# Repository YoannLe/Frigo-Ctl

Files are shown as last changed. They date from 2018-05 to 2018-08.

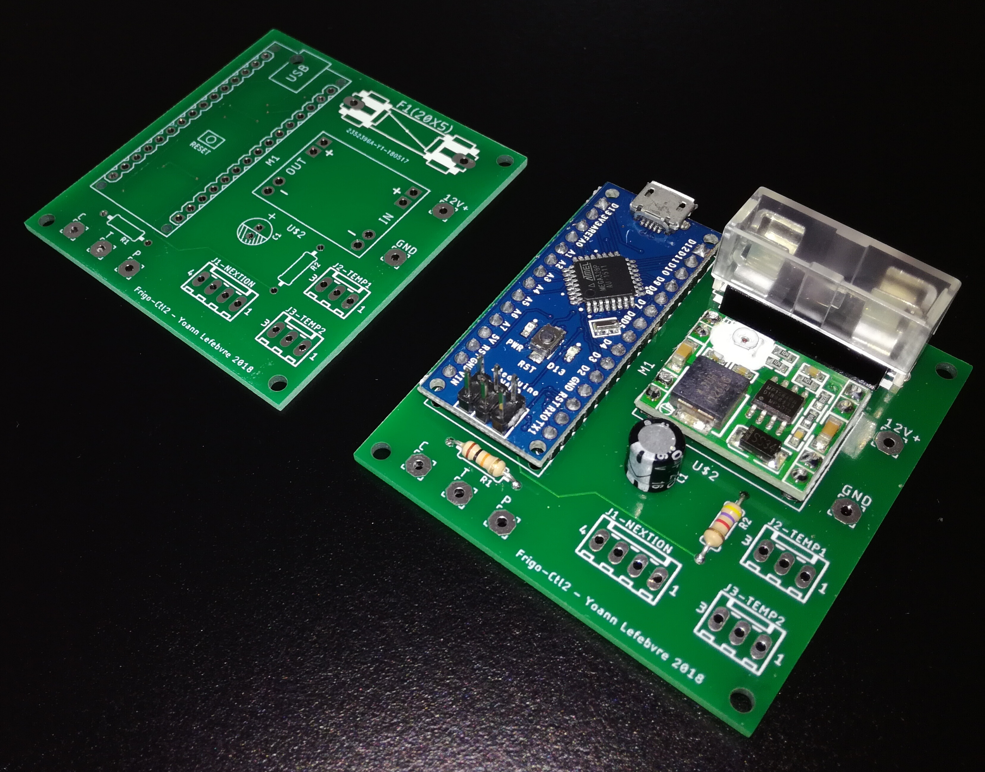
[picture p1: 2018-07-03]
Photos/IMG_20180608_055805.jpg

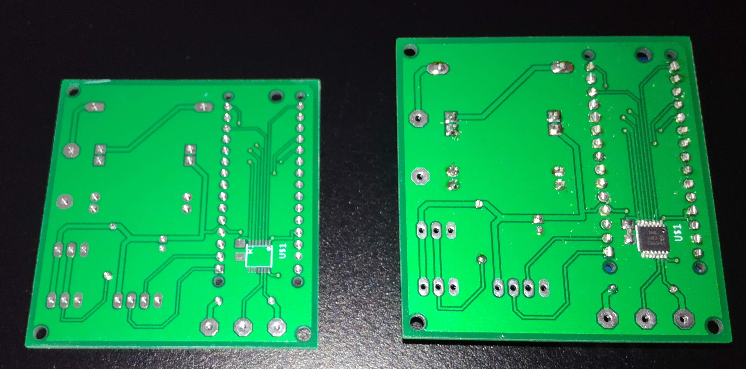
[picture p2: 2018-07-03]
Photos/IMG_20180602_103453.jpg

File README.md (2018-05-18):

# Frigo-Ctl
Arduino controller and thermostat with touch screen for 12V Fridge Compressor. Boat, RV, motorhome. To drive Danfoss, SECOP, vitrifrigo, 101N0212 compressors control units.

Compressors RPM, start and stop could be controled by resistors values and mechanical thermostat.

To set the best ratio between compressor speed and cold generation needed, the AOE protocol was developed on high end devices. This project coud genarate AOE control on a standard unit and specials functions like manual boost, graphic touch screen and DS18B20 temperature sensors.

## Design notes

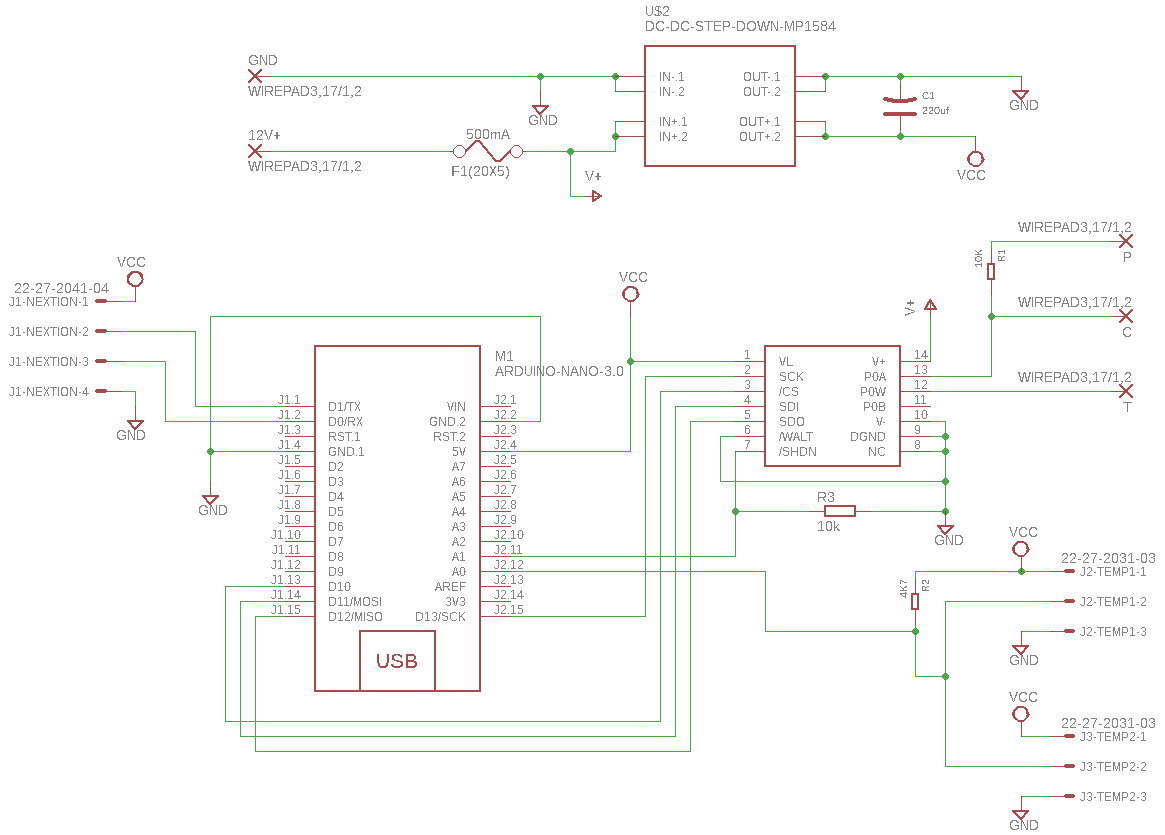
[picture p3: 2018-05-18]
PCB/Frigo-Ctl/Schematic.png

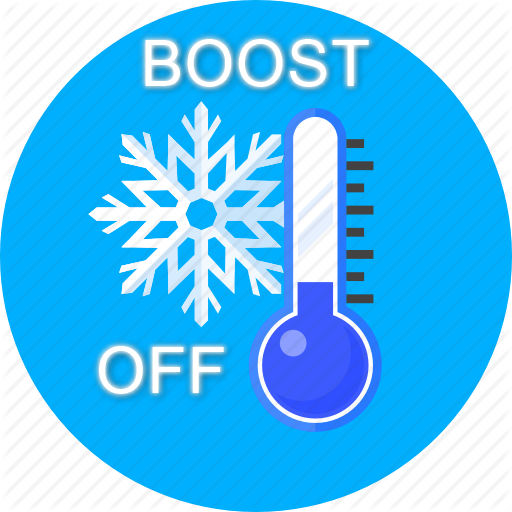
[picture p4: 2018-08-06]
Nextion/Images/Sources/Turbo-OFF.png

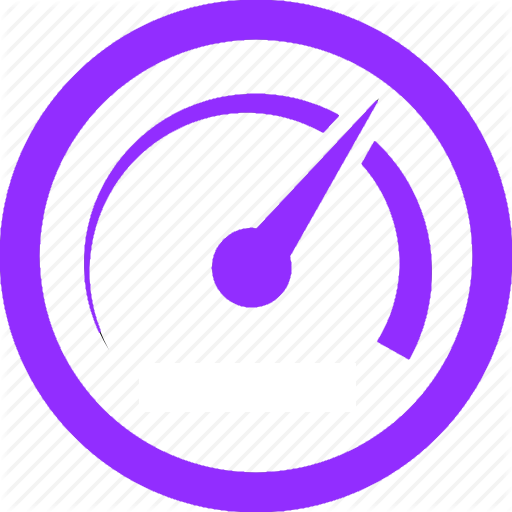
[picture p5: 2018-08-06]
Nextion/Images/Sources/RPM_Gauge-512.png

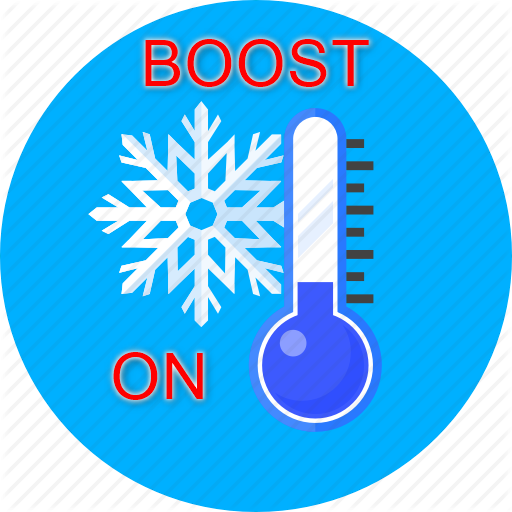
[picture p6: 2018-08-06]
Nextion/Images/Sources/Turbo-ON.png

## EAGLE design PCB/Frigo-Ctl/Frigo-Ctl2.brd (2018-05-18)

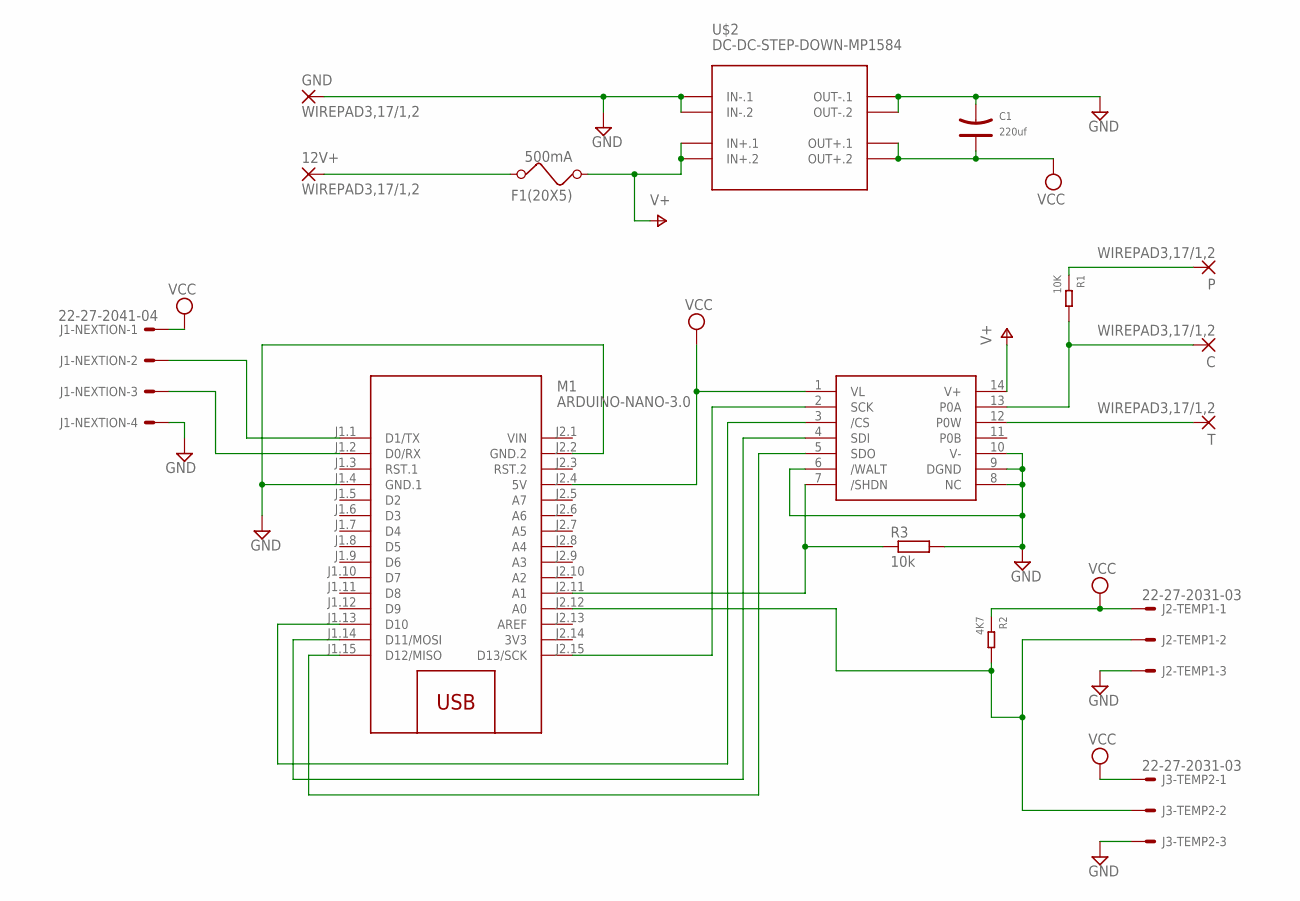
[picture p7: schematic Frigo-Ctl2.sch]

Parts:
12V+: WIREPAD3,17/1,2; 3,17/1,2
C: WIREPAD3,17/1,2; 3,17/1,2
C1: 220uf; PC-D5.3MM
F1(20X5): 500mA; FUSE
GND: WIREPAD3,17/1,2; 3,17/1,2
J1-NEXTION: 22-27-2041-04; 6410-04
J2-TEMP1, J3-TEMP2: 22-27-2031-03; 6410-03
M1: ARDUINO-NANO-3.0
P: WIREPAD3,17/1,2; 3,17/1,2
R1: 10K; PR-D2.3XL6.5MM
R2: 4K7; PR-D2.3XL6.5MM
R3: 10k; R1206
T: WIREPAD3,17/1,2; 3,17/1,2
U$1: MCP41HV51; TSSOP14
U$2: DC-DC-STEP-DOWN-MP1584

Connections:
3V3: M1.J2.14 (3V3)
GND: C1.-, GND.1, J1-NEXTION.4, J2-TEMP1.3, J3-TEMP2.3, M1.J1.4 (GND.1), M1.J2.2 (GND.2), R3.2, U$1.6 (/WALT), U$1.8 (NC), U$1.9 (DGND), U$1.10 (V-), U$2.IN-.1, U$2.IN-.2, U$2.OUT-.1, U$2.OUT-.2
unnamed: 12V+.1, F1(20X5).2
unnamed: M1.J2.11 (A1), R3.1, U$1.7 (/SHDN)
unnamed: J1-NEXTION.2, M1.J1.1 (D1/TX)
unnamed: J1-NEXTION.3, M1.J1.2 (D0/RX)
unnamed: C.1, R1.2, U$1.13 (P0A)
unnamed: P.1, R1.1
unnamed: M1.J1.13 (D10), U$1.3 (/CS)
unnamed: T.1, U$1.12 (P0W)
unnamed: M1.J2.15 (D13/SCK), U$1.2 (SCK)
unnamed: M1.J1.15 (D12/MISO), U$1.5 (SDO)
unnamed: M1.J1.14 (D11/MOSI), U$1.4 (SDI)
unnamed: J2-TEMP1.2, J3-TEMP2.2, M1.J2.12 (A0), R2.2
V+: F1(20X5).1, U$1.14 (V+), U$2.IN+.1, U$2.IN+.2
VCC: C1.+, J1-NEXTION.1, J2-TEMP1.1, J3-TEMP2.1, M1.J2.4 (5V), R2.1, U$1.1 (VL), U$2.OUT+.1, U$2.OUT+.2
VIN: M1.J2.1 (VIN)

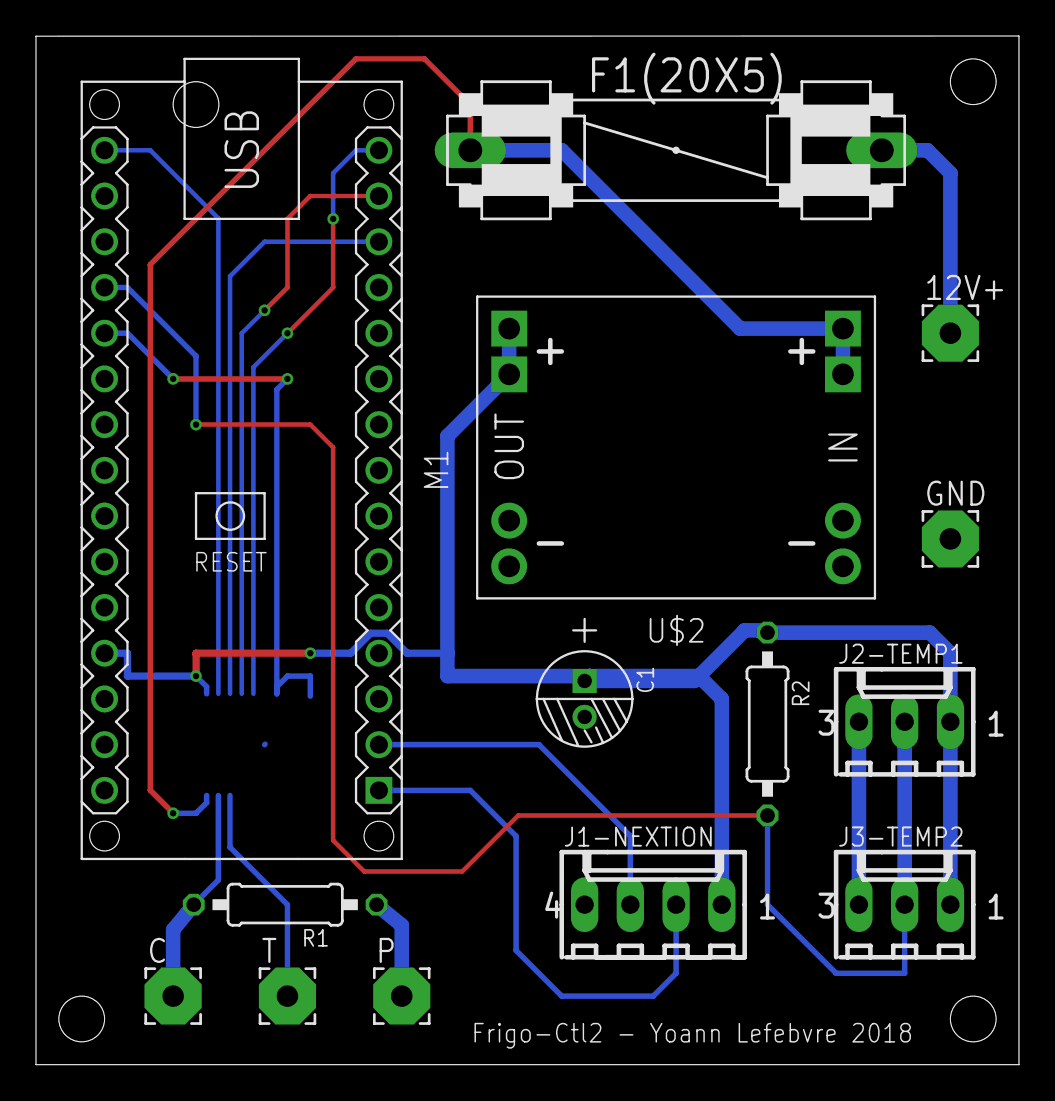
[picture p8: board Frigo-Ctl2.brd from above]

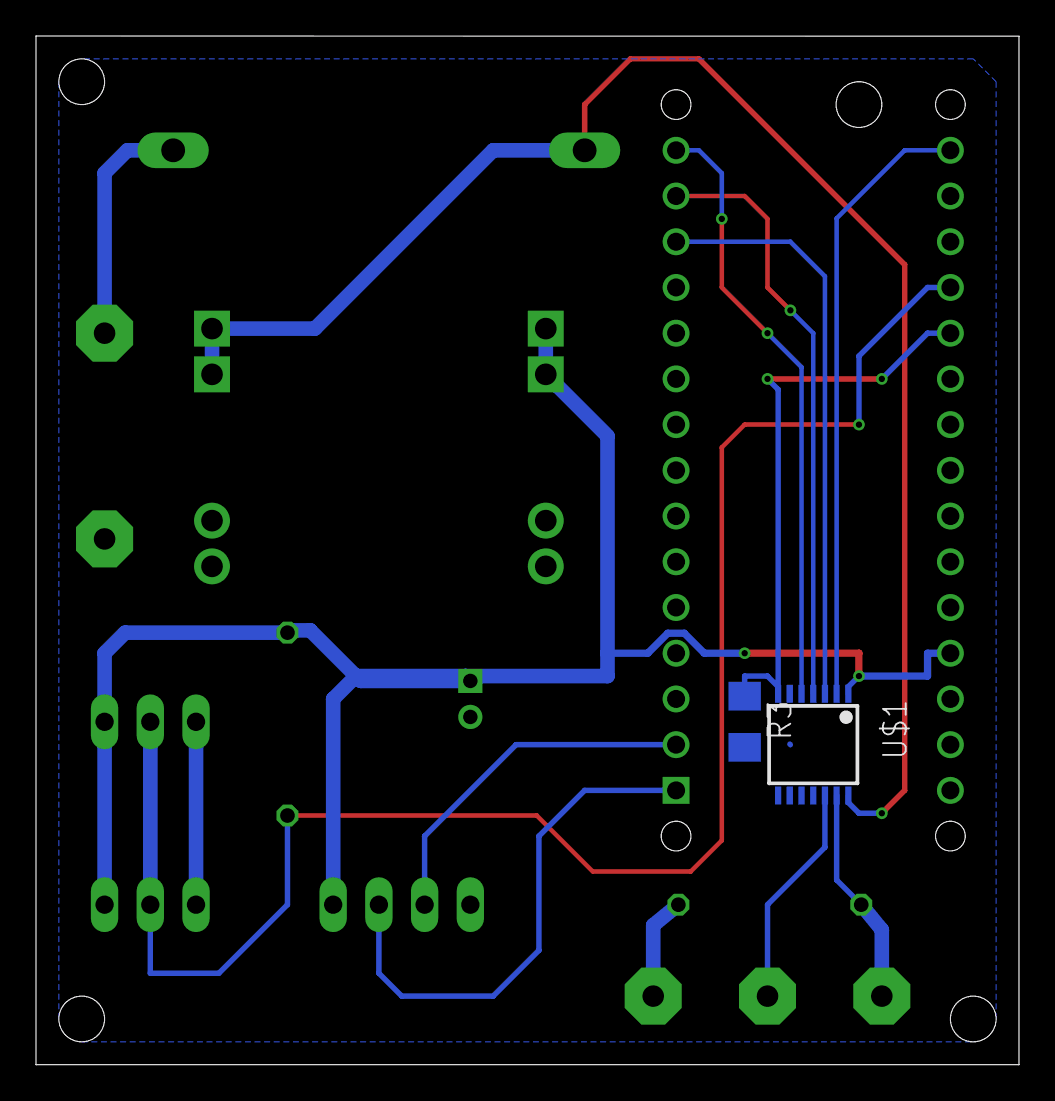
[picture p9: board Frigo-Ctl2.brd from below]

Board: 2 copper layers, 54.6 x 57.1 mm, 16 parts (2 on the bottom side), 15 nets.

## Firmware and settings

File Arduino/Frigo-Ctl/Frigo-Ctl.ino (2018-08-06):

// Disconnect Nextion to upload sketch to arduino.
// Hardware serial used, permits to trace serial coms with nextion via usb port of arduino and serial monitor
// can debug with NEXTION Simulator/Editor through Arduino USB
// Nextion charset ISO 8859-1 (latin-1)

#include <SimpleTimer.h>

//NEXTION

#include <Nextion.h>
#include <NextionPage.h>
#include <NextionVariableNumeric.h>
#include <NextionText.h>
#include <NextionNumber.h>
#include <NextionWaveform.h>
#include <NextionDualStateButton.h>
#include <SPI.h>
#include <OneWire.h>

#define NEXTION_PORT Serial

Nextion nex(NEXTION_PORT);

//NEXTION vars:
//NextionVariableNumeric varNexTempSet(nex, 0, 7, "TempSet"); //page 0, id 7
NextionVariableNumeric varVisWave(nex, 0, 26, "visWave"); //visWave id 26 -> check if waveform is visible

//NEXTION TXT:
NextionText txtNexTempFrig(nex, 0, 9, "TempFrigTxt");
NextionText txtNexTempCong(nex, 0, 10, "TempCongTxt");
NextionText txtNexTempSet(nex, 0, 8, "TempSetTxt");
//n0 id 2 : rpm
NextionNumber numNexRPM(nex, 0, 2, "n0");
//waveform ID 13 name s0
NextionWaveform graph(nex, 0, 13, "s0");
//Boost button state
NextionDualStateButton boostBt(nex, 0, 3, "bt0");

//Vars et const
float tempFrigDS;
float tempCongDs;
float tempSet = 4;
// Compressor entre 2000 et 3500
float   compresRPM=0;
float   compresRPMStart = 2500;
#define compresRPM_MIN 2200
#define compresResistorAt_MIN 0
#define compresRPM_MAX 3500
#define compresResistorAt_MAX 1523
#define potRw 180 // RW value depends on T°, Vres and Iw
#define coefRPM_Res (compresResistorAt_MAX-compresResistorAt_MIN)/(compresRPM_MAX-compresRPM_MIN)

#define compRPMRampSpeed 9.4
#define compresRPMafterBoost 2500
bool  boostUsed = 0;

//timer
SimpleTimer timer;

//DS18B20
OneWire  ds(A0);  // on pin A0 (a 4.7K resistor is necessary)
bool dsMesured = 0;
byte dsaddr1[8], dsaddr2[8];

// SPI MCP41HVX1
// MCP41100 connected to  arduino Board
// CS >>> D10
// SCLK >> D13
// DI  >>> D11
// 

byte address = 0x11;
#define CS 10       //D10
#define SHDWN 15    //A1
#define addr  0x00



void setup()
{
  NEXTION_PORT.begin(19200);
  nex.init();
  timer.setInterval(60000, setRPMandGraph); //toutes les minutes vitesse compresseur et graphe
  timer.setInterval(500, sendNex); //toutes les 500ms actualise l'affichage et valeur TempSet
  timer.setInterval(1500, getDsTemperature); //toutes les 1500ms mesure la température ou recupère les valeurs
  
  
  pinMode (CS, OUTPUT);
  pinMode (SHDWN, OUTPUT);
  digitalWrite(SHDWN, LOW); //coupe le compresseur
  
  SPI.begin();

  Serial.begin(19200);
  
  nex.poll();
  
}

void loop() {
  //toutes les minutes vitesse compresseur et graphe
  //toutes les 500ms actualise l'affichage
  //toutes les 1500ms mesure la température ou recupère les valeurs
  timer.run();

}


void setRPMandGraph()
{
  double graphVal;
  float tempRef;
  
   //Gestion vitesse compresseur et graphique toutes les minutes
  if(compresRPM == 0)
    // Compresseur éteint, attendre niveau tempSet+1°C avant start
    {
      tempRef = tempSet+1;
      if(tempFrigDS > tempRef)
      {
        compresRPM = compresRPMStart;
        digitalPotRPMWrite(compresRPM);
        digitalWrite(SHDWN, HIGH); //démarre le compresseur
      }
    }else{
    //Compresseur en route
      if(tempFrigDS > tempSet)
      //si température supérieure à tempsSet
      {
        // Compresseur en fonctionnement, application du ramp dans la limite du max
        if(compresRPM<compresRPM_MAX)
        {
          compresRPM = compresRPM+compRPMRampSpeed;
          digitalPotRPMWrite(compresRPM);
        }
        //activation du boost
        if(boostBt.isActive())
        {
          compresRPM = compresRPM_MAX;
          digitalPotRPMWrite(compresRPM);
          boostUsed =1;
        }else{
          //desactivation du boost
          if(boostUsed)
          {
            compresRPM = compresRPMafterBoost;
            digitalPotRPMWrite(compresRPM);
            boostUsed=0;
          }
        }
      }else{
        //archive rpm de stop - 300 rpm (systeme AOE)
        //sauf si boost, valeur de référence
        if(boostUsed == 1)
        {
          compresRPMStart = compresRPMafterBoost;
          boostUsed =0;
        }else{
          tempRef=compresRPM-300;
          if(tempRef>compresRPM_MIN)
          {
            compresRPMStart = compresRPM-300;
          }else{
            compresRPMStart = compresRPM_MIN;
          }
        }
        //stope le compresseur
        compresRPM=0;
        digitalWrite(SHDWN, LOW); //coupe le compresseur
      }
    }
  
  //actualisation graphique toutes les minutes 220pix
  if(compresRPM>1500)
  {
    graphVal = (compresRPM-1500)/2200;
    graphVal = graphVal*220;
  }else{
    graphVal = 0;
  }
  graph.addValue(0, graphVal);         //RPM max graph 1500 à 3700
  graphVal = tempFrigDS*(220/44)+110;
  if(graphVal > 220)
  {
    graphVal = 220;
  }
  if(graphVal < 0)
  {
    graphVal = 0;
  }
  graph.addValue(1, graphVal);       //Temp Frigo -22 à +22
  graphVal = tempCongDs*(220/44)+110;
  if(graphVal > 220)
  {
    graphVal = 220;
  }
  if(graphVal < 0)
  {
    graphVal = 0;
  }
  graph.addValue(2, graphVal);       //Temp congel
}

float getTempSet()
{
  String tempNex;
  char nexBuffer[10];

  txtNexTempSet.getText(nexBuffer,10);
  nex.poll();
  tempNex=String(nexBuffer);
  if(tempNex.indexOf(char(0xB0)) > -1)
  {
  tempNex.remove(tempNex.indexOf(char(0xB0)));
  }
  if(tempNex.indexOf('C') > -1)
  {
  tempNex.remove(tempNex.indexOf('C'));
  }
  if(tempNex.indexOf(' ') > -1)
  {
  tempNex.remove(tempNex.indexOf(' '));
  }
  return(tempNex.toFloat());
}


void sendNex() 
{
  String tempToNex;
  char nexBuffer[10];
  int visiWave=1;

  nex.poll();
  visiWave=varVisWave.getValue();
  tempSet=getTempSet();
  nex.poll();
  
  if(visiWave == 0)
  {
    numNexRPM.setValue(compresRPM);
        
    tempToNex = String(tempFrigDS,1);
    tempToNex = String(tempToNex + char(0xB0));
    tempToNex = String(tempToNex + "C");
    tempToNex.toCharArray(nexBuffer, 10);
    txtNexTempFrig.setText(nexBuffer);
      
    tempToNex = String(tempCongDs,1);
    tempToNex = String(tempToNex + char(0xB0));
    tempToNex = String(tempToNex + "C");
    tempToNex.toCharArray(nexBuffer, 10);
    txtNexTempCong.setText(nexBuffer);

    nex.refresh("TempCongTxt");
    nex.refresh("TempFrigTxt");
    nex.refresh("n0");
    
    //nex.sendCommand("vis TempCongTxt,1");
    //nex.sendCommand("vis TempFrigTxt,1");
    //nex.sendCommand("vis n0,1"); 
  }else{
    nex.refresh("s0");
  }
  nex.poll();
}

void digitalPotRPMWrite(float comRPM)
{
  //comRPM
  //2000 ->    0 Ohms / 5mA
  //2500 ->  277 Ohms / 4mA
  //3000 ->  692 Ohms / 3mA
  //3500 -> 1523 Ohms / 2mA
  // not linear but not realy a probleam
  // (1523-0)/(3500-2000)=1,015
  // 1,015*(2000-2000) = 0
  // 
  //255 = 0 Ohm
  //0   = 5 kOhms
  //Rw = 200 Ohm
  float resValue=0;

  resValue = coefRPM_Res*(comRPM-compresRPM_MIN);
  if(resValue>=potRw)
  {
    resValue=resValue-potRw;  // Rw offset correction
  }
  else
  {
    resValue=0;
  }
  resValue = resValue/(5000/255);
  resValue = int(resValue);
  resValue = 255-resValue;
  digitalWrite(CS, LOW);
  SPI.transfer(addr);
  SPI.transfer(resValue);
  digitalWrite(CS, HIGH);
}

/**
 * Fonction de lecture de la température via un capteur DS18B20.
 */
void getDsTemperature(void)
{
  byte data[9];
  // data[] : Données lues depuis le scratchpad
  // dsaddr1[] : Adresse du module 1-Wire détecté
  // dsaddr2[] : Adresse du module 1-Wire détecté
  // tempFrigDS
  // tempCongDs

  if (!dsMesured)
    {
    /* Reset le bus 1-Wire ci nécessaire (requis pour la lecture du premier capteur) */
    ds.reset();
    ds.reset_search();
  
    /* Recherche le prochain capteur 1-Wire disponible */
    ds.search(dsaddr1);
    ds.search(dsaddr2);
    
    /* Reset le bus 1-Wire et sélectionne le capteur */
    /* Lance une prise de mesure de température et attend la fin de la mesure */
    ds.reset();
    ds.select(dsaddr1);
    ds.write(0x44, 1);
    
    ds.reset();
    ds.select(dsaddr2);
    ds.write(0x44, 1);

    dsMesured = 1;
    //delay(800);
  }
  else
  {
    /* Reset le bus 1-Wire, sélectionne le capteur et envoie une demande de lecture du scratchpad */
    ds.reset();
    ds.select(dsaddr1);
    ds.write(0xBE);
   
   /* Lecture du scratchpad */
    for (byte i = 0; i < 9; i++) {
      data[i] = ds.read();
    }
     
    /* Calcul de la température en degré Celsius */
    tempFrigDS = (int16_t) ((data[1] << 8) | data[0]) * 0.0625; 
  
      /* Reset le bus 1-Wire, sélectionne le capteur et envoie une demande de lecture du scratchpad */
    ds.reset();
    ds.select(dsaddr2);
    ds.write(0xBE);
   
   /* Lecture du scratchpad */
    for (byte i = 0; i < 9; i++) {
      data[i] = ds.read();
    }
     
    /* Calcul de la température en degré Celsius */
    tempCongDs = (int16_t) ((data[1] << 8) | data[0]) * 0.0625; 
    
    dsMesured = 0;
  }
  
}

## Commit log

2018-05-18 First upload, board schematic, PCB, Gerber and datasheets
    [Frigo-Ctl2.GBL, Frigo-Ctl2.GBO, Frigo-Ctl2.GBP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]
2018-07-03 Pictures of PCB

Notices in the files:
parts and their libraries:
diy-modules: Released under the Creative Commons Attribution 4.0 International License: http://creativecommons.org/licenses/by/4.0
